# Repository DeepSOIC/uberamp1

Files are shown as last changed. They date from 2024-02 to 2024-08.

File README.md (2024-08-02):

# Feautures

* output channels: 8 independent(*) single-ended power outputs (TPA3255) + 2 headphone-amplified output channels + 2 non-amplified adau1701 dacs
    * independent 8 single-ended outputs can be arbitrarily combined into btl or even 3-phase-like arrangements.
    * BTL protections of the tpa chip can be enabled with solder bridges on the board
* two tpa3255 amps with full coverage of their supply range and peak output current(**)
* easy-to-program yet flexible adau1701 dsp chip, with self-boot memory on the board
* low-noise AK4454 dacs allow to use the full 113db(***) of dynamic range of the TPA3255
* 2 "feedbass" amplifiers on board, and places for resistors for custom analog mixing of feedbass into outputs.
* capacitor-free analog signal path (except analog inputs) allows to output dc, so uberamp1 can be used to drive motors
* 2 analog input channels
* bluetooth receiver with digital connection to the dsp (firmware = TODO)
* pads for summing inputs for each amp channel to allow adding custom analog feedbacks

(*) there is no place for decoupling capacitors on the board. So you might use one of the outputs as "ground", leaving you with 7 channels. In BTL, there are 4 output channels.

(**) at high supply voltage or high load currents, heatsinking becomes a challenge. It dissipates about 11W total in silence at 48 V.

(***) 113db is for BTL only. In SE mode, or across amps, the dynamic range of TPA3255 is much lower at 101 db.

# known problems (v1):

* power amps don't start exactly in sync, causing large excursion at powerup if a speaker is connected between amps. Seems unfixable.
* i don't have a good heat sink solution yet.
* dacs don't start up if the supply is raised slowly. Can be fixed with a bodge wire connecting "pg" net to "pd" pins of the dac chips
* it is very challenging to solder.

# soldering 

TLDR: manufacturability is screwed up on v1.

While the board was designed for hand-soldering, the footprints for 0603 passives turned out to not work well for hand-soldering.
It is further exacerbated by some bad placements - some pads are unreachable with a reasonable soldering iron. 
It seems that a lot of 0603 footprints can instead be populated with 0402 parts, that should make hand-soldering somewhat easier...

Reflow soldering for passives whould probably work well... but some other foorprints are completely unusable for reflow soldering.

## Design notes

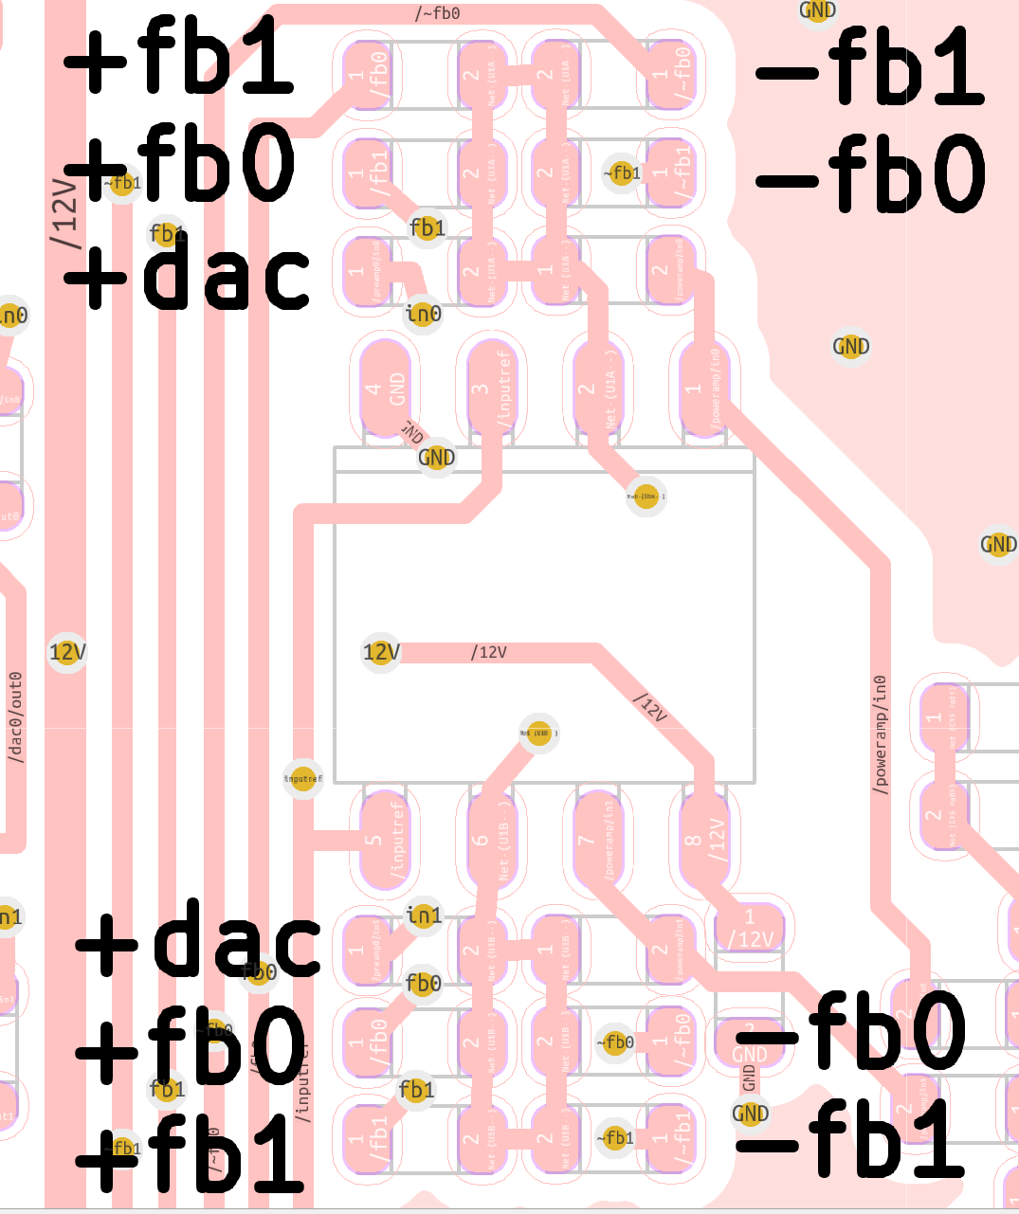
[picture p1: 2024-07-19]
summation resistor layout.png

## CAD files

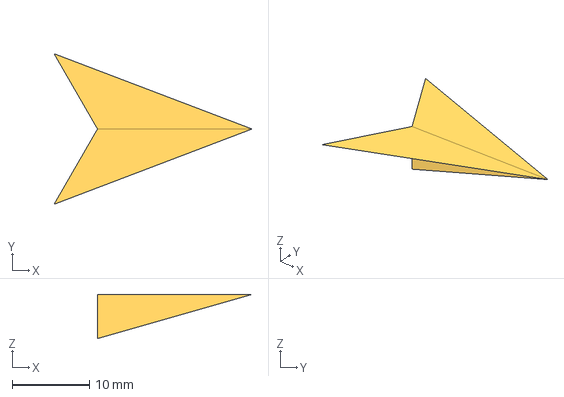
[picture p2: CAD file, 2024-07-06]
board outline.FCStd
25.6 x 19.5 x 5.71 mm

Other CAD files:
board outline.dxf

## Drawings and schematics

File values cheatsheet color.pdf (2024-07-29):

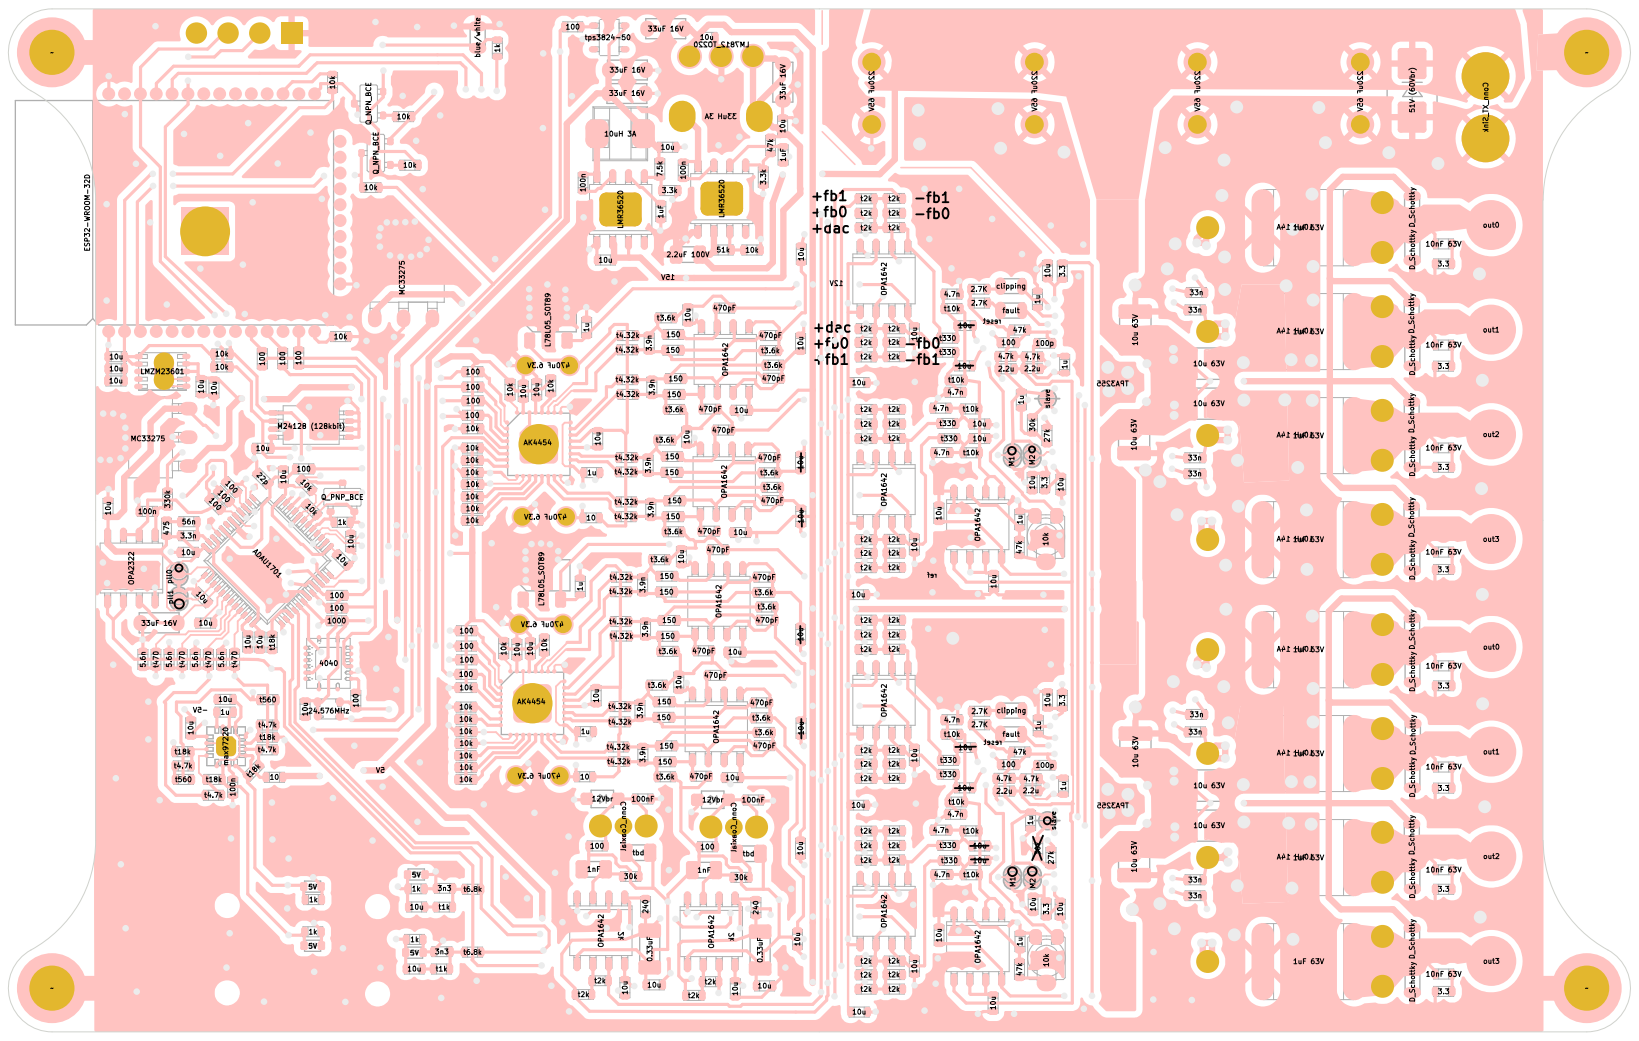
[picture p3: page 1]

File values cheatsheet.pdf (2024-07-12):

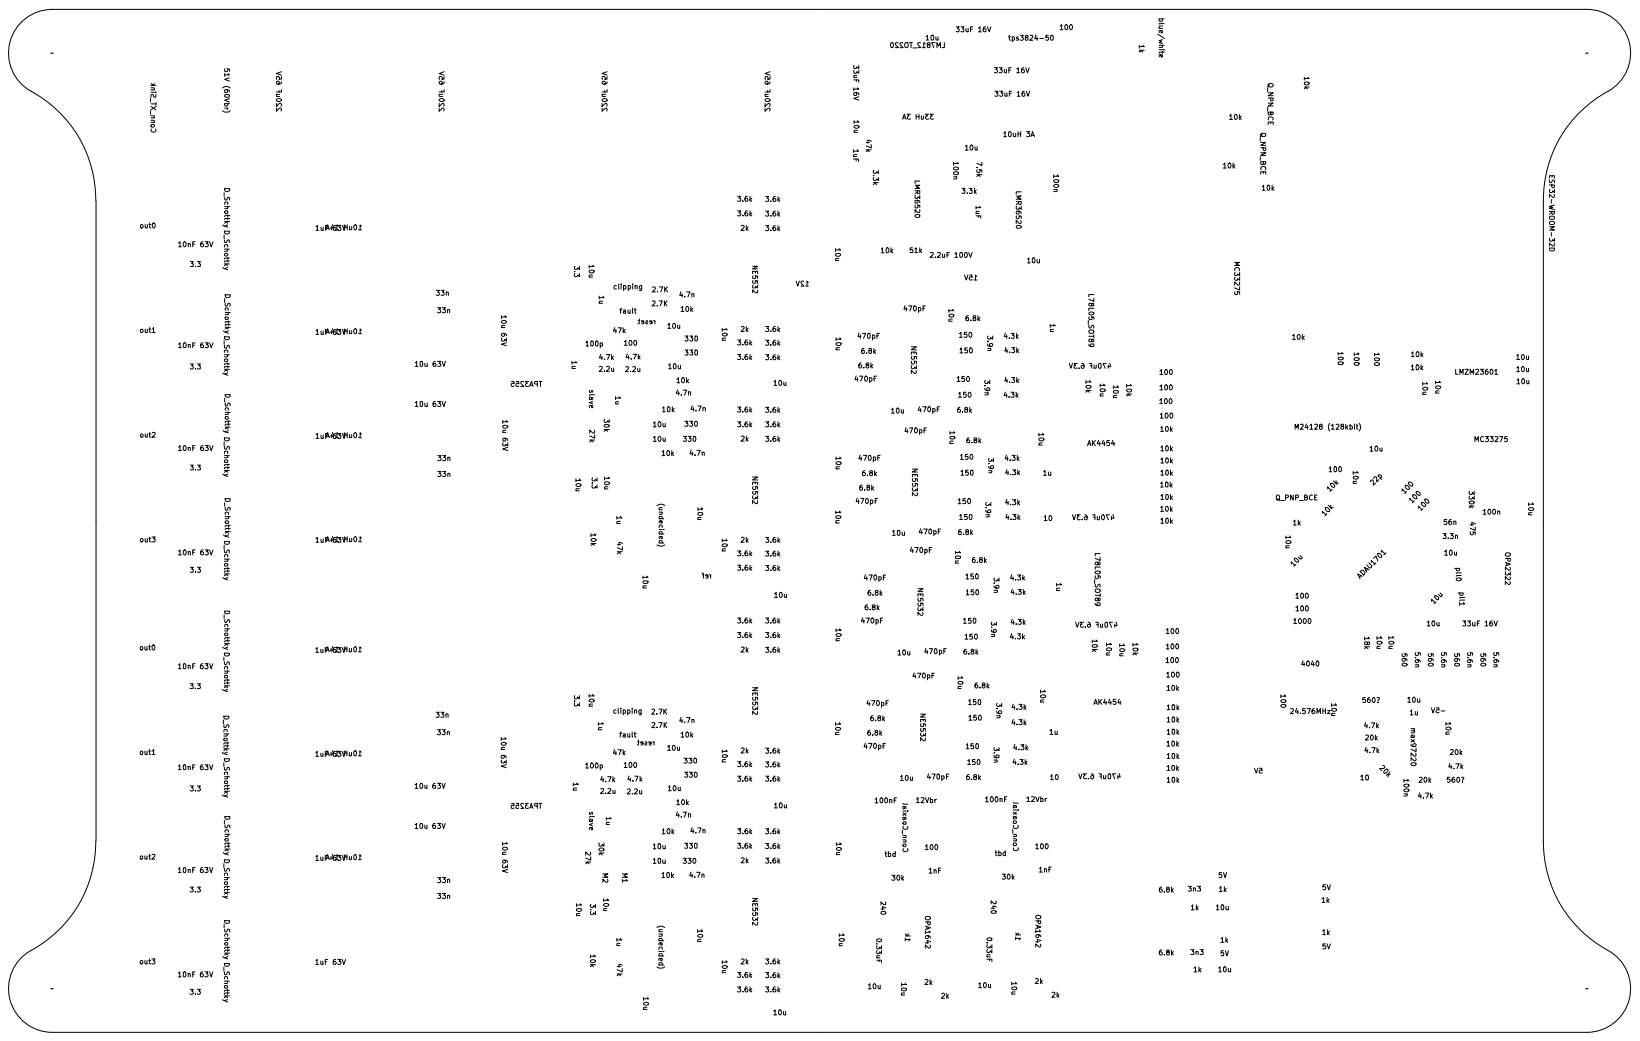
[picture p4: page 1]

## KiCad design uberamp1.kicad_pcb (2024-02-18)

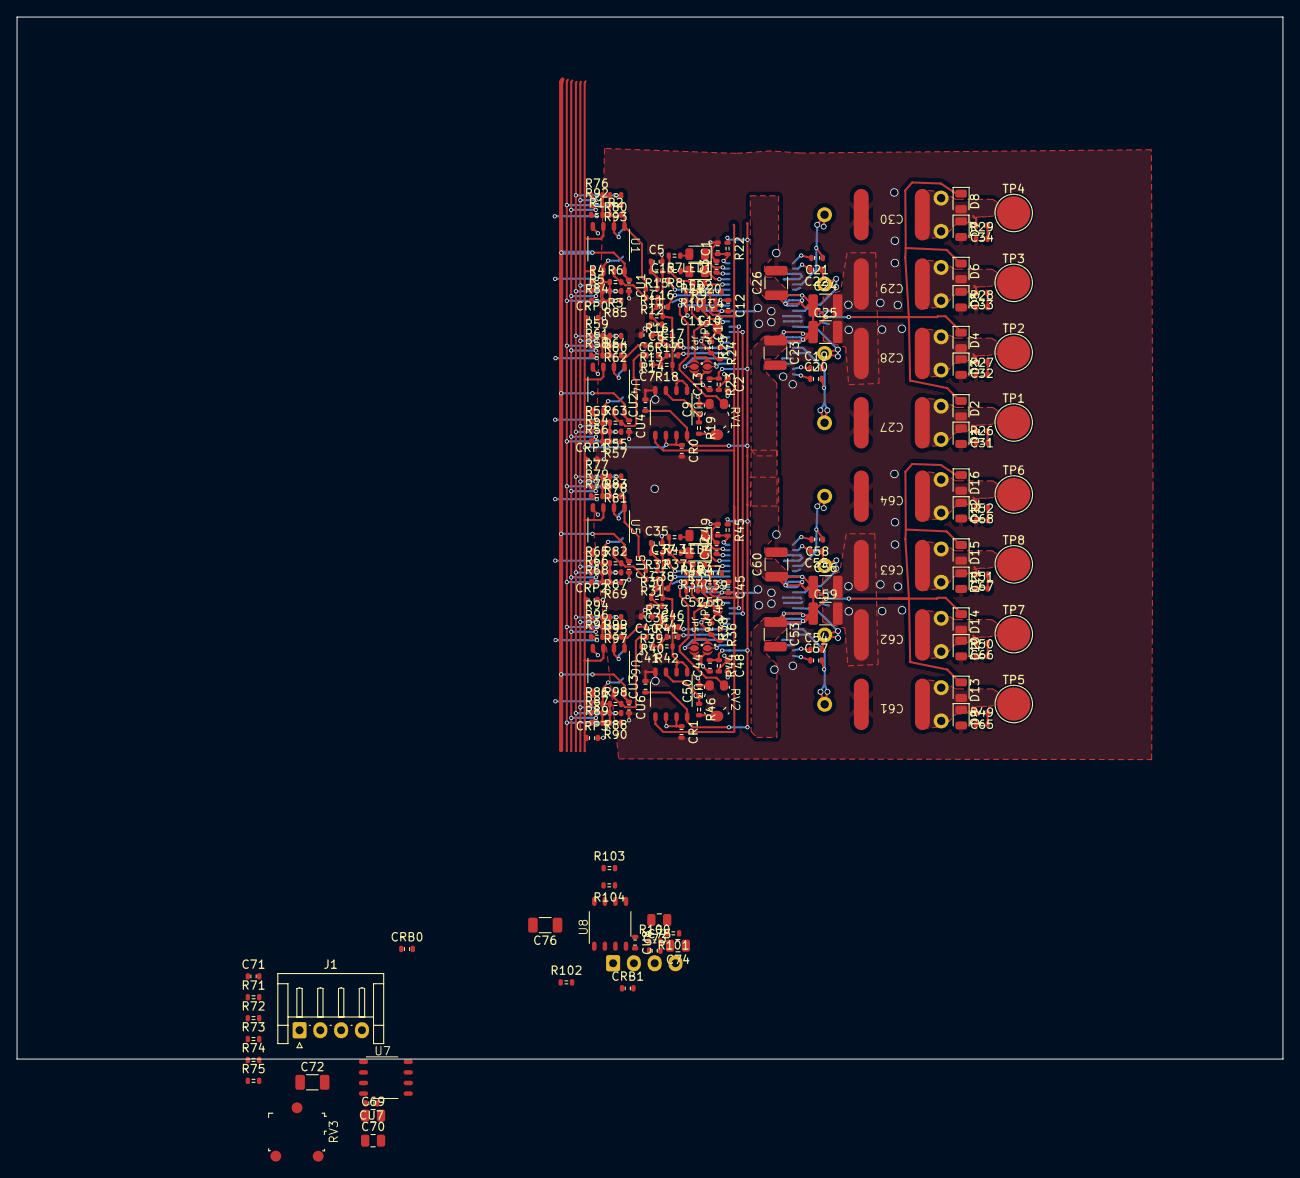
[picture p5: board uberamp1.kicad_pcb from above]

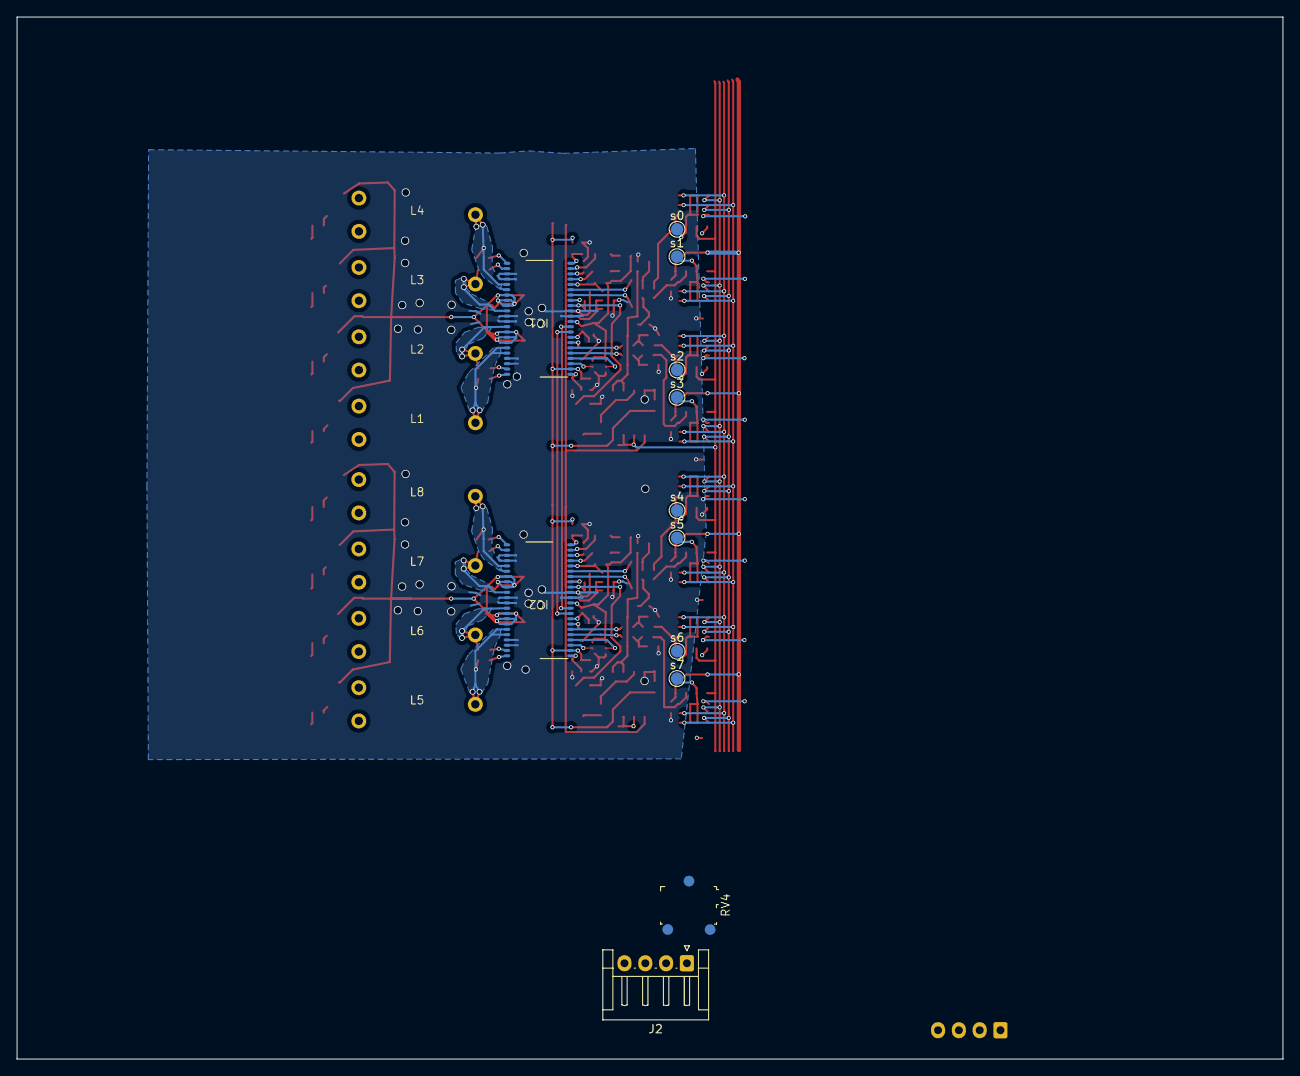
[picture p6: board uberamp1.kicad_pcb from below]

Board: 2 copper layers, 152.1 x 125.2 mm, 262 parts (20 on the bottom side), 124 nets.

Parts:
C1, C2, C13, C15, C16, C17, C18, C37, C38, C44, C46, C47, C48, C49: 10u; C_0603
C3, C9, C12, C42, C45, C50: 1u; C_0603
C4, C39: 100p; C_0603
C5, C6, C7, C8, C35, C36, C40, C41: 4.7n; C_0603
C10, C11, C51, C52: 2.2u; C_0603
C14, C43: 1uF; C_0603
C19, C20, C21, C22, C54, C55, C57, C58: 33n; C_0603
C23, C24, C25, C26, C53, C56, C59, C60: 10u 63V; C_1210_3225Metric
C27, C28, C29, C30, C61, C62, C63, C64: 1uF 63V; CB052D0105KBC film cap
C31, C32, C33, C34, C65, C66, C67, C68: 10nF; C_0603
C69, C74: tbd; C_0805_2012Metric
C70, C75: 1nF; C_0805_2012Metric
C71, C73: 100nF; C_0603
C72, C76: 0.33uF; C_1206_3216Metric
CR0, CR1: 10u; C_0603
CRB0, CRB1: 10u; C_0603
CRP0, CRP1, CRP2, CRP3: 10u; C_0603
CU1, CU2, CU3, CU4, CU5, CU6, CU7, CU8: 10u; C_0603
D1, D2, D3, D4, D5, D6, D7, D8, D9, D10, D11, D12, D13, D14, D15, D16: D_Schottky; D_0805_2012Metric
IC1, IC2: TPA3255; tssop44-powerpad
J1, J2: Conn_01x04; JST_EH_S4B-EH_1x04_P2.50mm_Horizontal
JP1, JP2, JP5, JP6: SolderJumper_3_Bridged12; solder-switch
JP3, JP4: slave; solder-jumper
L1, L2, L3, L4, L5, L6, L7, L8: 10uH 14A; SPM12565VT-D-vertical
LED1, LED4: clipping; LED_0805_2012Metric
LED2, LED3: fault; LED_0805_2012Metric
R1, R4, R53, R58, R65, R70, R86, R91: R_Small; R_0603
R2, R6, R63, R64, R71, R72, R82, R83, R98, R99, R103, R104: 2k; R_0603
R3, R5, R54, R55, R56, R57, R59, R60, R61, R62, R66, R67, R68, R69, R76, R77, R78, R79, R80, R81, R84, R85, R87, R88, R89, R90, R92, R93, R94, R95, R96, R97: 3.6k; R_0603
R7, R8, R37, R43: 2.7K; R_0603
R9, R19, R35, R46: 47k; R_0603
R10, R34, R75, R100: 100; R_0603
R11, R12, R13, R14, R30, R31, R39, R40: 330; R_0603
R15, R16, R17, R18, R32, R33, R41, R42: 10k; R_0603
R20, R21, R47, R48: 4.7k; R_0603
R22, R23, R26, R27, R28, R29, R44, R45, R49, R50, R51, R52: 3.3; R_0603
R24, R36: 27k; R_0603
R25, R38, R73, R101: 30k; R_0603
R74, R102: 240; R_0603
RV1, RV2: 10k; TC33X-2 trimpot
RV3, RV4: 1k; PV37X
TP1, TP5: out3; TestPoint_Pad_D4.0mm
TP2, TP7: out2; TestPoint_Pad_D4.0mm
TP3, TP8: out1; TestPoint_Pad_D4.0mm
TP4, TP6: out0; TestPoint_Pad_D4.0mm
U1, U2, U3, U4, U5, U6, U7, U8: Opamp_Dual; SOIC-8
s0, s1, s2, s3, s4, s5, s6, s7: sum0; TestPoint_Pad_D1.5mm

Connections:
/12V: C13.2, C44.2, CU1.1, CU2.1, CU3.1, CU4.1, CU5.1, CU6.1, CU7.1, CU8.1, IC1.2 (2_VDD), IC2.2 (2_VDD), R22.1, R23.1, R44.1, R45.1, U1.8 (V+), U2.8 (V+), U3.8 (V+), U4.8 (V+), U5.8 (V+), U6.8 (V+), U7.8 (V+), U8.8 (V+)
/fb0: C72.1, R5.1, R54.1, R59.1, R66.1, R71.1, R74.2, R76.1, R77.1, R87.1, R94.1
/fb1: C76.1, R56.1, R61.1, R68.1, R79.1, R84.1, R89.1, R92.1, R96.1, R102.2, R103.1
/inputref: C69.2, C70.2, C72.2, C74.2, C75.2, C76.2, CR0.1, CRB0.1, CRB1.1, CRP0.1, CRP1.1, CRP2.1, CRP3.1, R75.2, R100.2, RV3.3, RV4.3, U1.3 (+), U1.5 (+), U2.6 (-), U2.7, U4.3 (+), U4.5 (+), U5.3 (+), U5.5 (+), U6.3 (+), U6.5 (+), U7.5 (+), U8.5 (+)
/poweramp1/AVDD: C51.1, IC2.14 (14_AVDD), R47.2, RV2.3
/poweramp1/DVDD: C43.1, IC2.11 (11_DVDD), JP4.2 (B), JP5.1 (A), JP6.1 (A), R35.2, R37.2, R43.2
/poweramp1/in0: R30.2, R83.2, U5.1
/poweramp1/in1: R31.2, R82.2, U5.7
/poweramp1/in2: R39.2, R99.2, U6.1
/poweramp1/in3: R40.2, R98.2, U6.7
/poweramp1/in_a: C47.2, IC2.5 (5_INPUT_A)
/poweramp1/in_b: C46.2, IC2.6 (6_INPUT_B)
/poweramp1/in_c: C38.2, IC2.16 (16_INPUT_C)
/poweramp1/in_d: C37.2, IC2.17 (17_INPUT_D)
/poweramp1/input_ref: CR1.1, U3.6 (-), U3.7
/poweramp1/out0: C64.1, C68.2, D12.1 (K), D16.2 (A), L8.1, TP6.1
/poweramp1/out1: C63.1, C67.2, D11.1 (K), D15.2 (A), L7.1, TP8.1
/poweramp1/out2: C62.1, C66.2, D10.1 (K), D14.2 (A), L6.1, TP7.1
/poweramp1/out3: C61.1, C65.2, D9.1 (K), D13.2 (A), L5.1, TP5.1
/poweramp1/sw0: C58.1, IC2.27 (27_OUT_D), IC2.28 (28_OUT_D____________), L8.2
/poweramp1/sw1: C55.1, IC2.32 (32_OUT_C), L7.2
/poweramp1/sw2: C54.2, IC2.35 (35_OUT_B), L6.2
/poweramp1/sw3: C57.2, IC2.39 (39_OUT_A), IC2.40 (40_OUT_A____________), L5.2
/poweramp1/trim: R32.1, R33.1, R41.1, R42.1, U3.1, U3.2 (-)
/poweramp/AVDD: C10.1, IC1.14 (14_AVDD), R20.2, RV1.3
/poweramp/DVDD: C14.1, IC1.11 (11_DVDD), JP1.1 (A), JP2.1 (A), JP3.2 (B), R7.2, R8.2, R9.2
/poweramp/in0: R2.2, R11.2, U1.1
/poweramp/in1: R6.2, R12.2, U1.7
/poweramp/in2: R13.2, R64.2, U4.1
/poweramp/in3: R14.2, R63.2, U4.7
/poweramp/in_a: C18.2, IC1.5 (5_INPUT_A)
/poweramp/in_b: C17.2, IC1.6 (6_INPUT_B)
/poweramp/in_c: C16.2, IC1.16 (16_INPUT_C)
/poweramp/in_d: C15.2, IC1.17 (17_INPUT_D)
/poweramp/input_ref_z: C10.2, C11.1, C51.2, C52.1, R20.1, R21.2, R47.1, R48.2, U2.5 (+), U3.5 (+)
/poweramp/osc+: IC1.10 (10_OSC_IOP), IC2.10 (10_OSC_IOP)
/poweramp/osc-: IC1.9 (9_OSC_IOM), IC2.9 (9_OSC_IOM)
/poweramp/out0: C30.1, C34.2, D7.1 (K), D8.2 (A), L4.1, TP4.1
/poweramp/out1: C29.1, C33.2, D5.1 (K), D6.2 (A), L3.1, TP3.1
/poweramp/out2: C28.1, C32.2, D3.1 (K), D4.2 (A), L2.1, TP2.1
/poweramp/out3: C27.1, C31.2, D1.1 (K), D2.2 (A), L1.1, TP1.1
/poweramp/sw0: C21.1, IC1.27 (27_OUT_D), IC1.28 (28_OUT_D____________), L4.2
/poweramp/sw1: C22.1, IC1.32 (32_OUT_C), L3.2
/poweramp/sw2: C19.2, IC1.35 (35_OUT_B), L2.2
/poweramp/sw3: C20.2, IC1.39 (39_OUT_A), IC1.40 (40_OUT_A____________), L1.2
/poweramp/trim: R15.1, R16.1, R17.1, R18.1, U2.1, U2.2 (-)
/~fb0: R3.1, R55.1, R60.1, R67.1, R72.2, R78.1, R80.1, R88.1, R95.1, U7.7
/~fb1: R57.1, R62.1, R69.1, R81.1, R85.1, R90.1, R93.1, R97.1, R104.2, U8.7
GND: C1.2, C2.2, C3.2, C4.2, C5.2, C6.2, C7.2, C8.2, C9.2, C11.2, C12.2, C13.1, C14.2, C23.2, C24.2, C25.2, C26.2, C27.2, C28.2, C29.2, C30.2, C35.2, C36.2, C39.2, C40.2, C41.2, C42.2, C43.2, C44.1, C45.2, C48.2, C49.2, C50.2, C52.2, C53.2, C56.2, C59.2, C60.2, C61.2, C62.2, C63.2, C64.2, C71.2, C73.2, CR0.2, CR1.2, CRB0.2, CRB1.2, CRP0.2, CRP1.2, CRP2.2, CRP3.2, CU1.2, CU2.2, CU3.2, CU4.2, CU5.2, CU6.2, CU7.2, CU8.2, D1.2 (A), D3.2 (A), D5.2 (A), D7.2 (A), D9.2 (A), D10.2 (A), D11.2 (A), D12.2 (A), IC1.12 (12_GND), IC1.13 (13_GND), IC1.25 (25_GND), IC1.26 (26_GND), IC1.33 (33_GND), IC1.34 (34_GND), IC1.41 (41_GND), IC1.42 (42_GND), IC2.12 (12_GND), IC2.13 (13_GND), IC2.25 (25_GND), IC2.26 (26_GND), IC2.33 (33_GND), IC2.34 (34_GND), IC2.41 (41_GND), IC2.42 (42_GND), JP1.3 (B), JP2.3 (B), JP5.3 (B), JP6.3 (B), R21.1, R24.2, R25.2, R26.1, R27.1, R28.1, R29.1, R36.2, R38.2, R48.1, R49.1, R50.1, R51.1, R52.1, RV1.1, RV2.1, U1.4 (V-), U2.4 (V-), U3.4 (V-), U4.4 (V-), U5.4 (V-), U6.4 (V-), U7.4 (V-), U8.4 (V-)
unnamed: C5.1, C15.1, R11.1, R15.2
unnamed: C8.1, C16.1, R12.1, R16.2
unnamed: C6.1, C17.1, R13.1, R17.2
unnamed: C7.1, C18.1, R14.1, R18.2
unnamed: C31.1, R26.2
unnamed: C32.1, R27.2
unnamed: C33.1, R28.2
unnamed: C34.1, R29.2
unnamed: C35.1, C37.1, R30.1, R32.2
unnamed: C36.1, C38.1, R31.1, R33.2
unnamed: C40.1, C46.1, R39.1, R41.2
unnamed: C41.1, C47.1, R40.1, R42.2
unnamed: C65.1, R49.2
unnamed: C66.1, R50.2
unnamed: C67.1, R51.2
unnamed: C68.1, R52.2
unnamed: C2.1, IC1.1 (1_GVDD_AB), R23.2
unnamed: IC1.3 (3_M1), JP1.2 (C)
unnamed: IC1.4 (4_M2), JP2.2 (C)
unnamed: IC1.7 (7_OC_ADJ), R24.1
unnamed: IC1.8 (8_FREQ_ADG), JP3.1 (A), R25.1
unnamed: C12.1, IC1.15 (15_C_START)
unnamed: C4.1, IC1.18 (18_RESET), R9.1, R10.1
unnamed: IC1.19 (19_FAULT), LED2.1 (K)
unnamed: C3.1, IC1.20 (20_VBG)
unnamed: IC1.21 (21_CLIP_OTW), LED1.1 (K)
unnamed: C1.1, IC1.22 (22GVDD_CD), R22.2
unnamed: C21.2, IC1.23 (23_BST_D)
unnamed: C22.2, IC1.24 (24_BST_C)
unnamed: C19.1, IC1.43 (43_BST_B)
unnamed: C20.1, IC1.44 (44_BST_A)
unnamed: C48.1, IC2.1 (1_GVDD_AB), R44.2
unnamed: IC2.3 (3_M1), JP6.2 (C)
unnamed: IC2.4 (4_M2), JP5.2 (C)
unnamed: IC2.7 (7_OC_ADJ), R36.1
unnamed: IC2.8 (8_FREQ_ADG), JP4.1 (A), R38.1
unnamed: C45.1, IC2.15 (15_C_START)
unnamed: C39.1, IC2.18 (18_RESET), R34.1, R35.1
unnamed: IC2.19 (19_FAULT), LED3.1 (K)
unnamed: C42.1, IC2.20 (20_VBG)
unnamed: IC2.21 (21_CLIP_OTW), LED4.1 (K)
unnamed: C49.1, IC2.22 (22GVDD_CD), R45.2
unnamed: C58.2, IC2.23 (23_BST_D)
unnamed: C55.2, IC2.24 (24_BST_C)
unnamed: C54.1, IC2.43 (43_BST_B)
unnamed: C57.1, IC2.44 (44_BST_A)
unnamed: C71.1, J1.3, R75.1
unnamed: C69.1, J1.4, R73.1
unnamed: C73.1, J2.3, R100.1
unnamed: C74.1, J2.4, R101.1
unnamed: LED1.2 (A), R7.1
unnamed: LED2.2 (A), R8.1
unnamed: LED3.2 (A), R37.1
unnamed: LED4.2 (A), R43.1
unnamed: R19.2, RV1.2
unnamed: R46.2, RV2.2
unnamed: R74.1, RV3.1, U7.1
unnamed: R102.1, RV4.1, U8.1
unnamed: R1.2, R2.1, R76.2, R80.2, R92.2, R93.2, U1.2 (-), s0.1
unnamed: R3.2, R4.2, R5.2, R6.1, R84.2, R85.2, U1.6 (-), s1.1
unnamed: C9.1, R19.1, U2.3 (+)
unnamed: C50.1, R46.1, U3.3 (+)
unnamed: R58.2, R59.2, R60.2, R61.2, R62.2, R64.1, U4.2 (-), s2.1
unnamed: R53.2, R54.2, R55.2, R56.2, R57.2, R63.1, U4.6 (-), s3.1
unnamed: R70.2, R77.2, R78.2, R79.2, R81.2, R83.1, U5.2 (-), s4.1
unnamed: R65.2, R66.2, R67.2, R68.2, R69.2, R82.1, U5.6 (-), s5.1
unnamed: R91.2, R94.2, R95.2, R96.2, R97.2, R99.1, U6.2 (-), s6.1
unnamed: R86.2, R87.2, R88.2, R89.2, R90.2, R98.1, U6.6 (-), s7.1
unnamed: C70.1, R73.2, U7.3 (+)
unnamed: RV3.2, U7.2 (-)
unnamed: R71.2, R72.1, U7.6 (-)
unnamed: C75.1, R101.2, U8.3 (+)
unnamed: RV4.2, U8.2 (-)
unnamed: R103.2, R104.1, U8.6 (-)
PVDD: C23.1, C24.1, C25.1, C26.1, C53.1, C56.1, C59.1, C60.1, D2.1 (K), D4.1 (K), D6.1 (K), D8.1 (K), D13.1 (K), D14.1 (K), D15.1 (K), D16.1 (K), IC1.29 (29_PVDD_CD), IC1.30 (30_PVDD_CD), IC1.31 (31_PVDD_CD), IC1.36 (36_PVDD_AB), IC1.37 (37_PVDD_AB), IC1.38 (38_PVDD_AB), IC2.29 (29_PVDD_CD), IC2.30 (30_PVDD_CD), IC2.31 (31_PVDD_CD), IC2.36 (36_PVDD_AB), IC2.37 (37_PVDD_AB), IC2.38 (38_PVDD_AB)

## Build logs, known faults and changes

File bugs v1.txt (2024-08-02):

bugs:
* all gains wrong because 8.8vpp is unachievable because fakegnd is only 3.82V
* NE5532 unusable (can't quite swing close enough to ground - need to reach 1.44 V, promised only 2 V). Using OPA1642 for now.
* with modified gains, the overall gain seems to be excessive. (check again!)
* r187 wrong value, should be 13k
* ak4454 NEEDS pg signal, otherwise it fails to start when supply raises slowly
* middle cap next to adau is very hard to solder
* caps to the left of dac amp are difficult to solder
* 10u caps are a bit larger than the footprint
* wrong footprint ak caps
* consider using 0402 on my 0603 footprints
* revise jack footprint:
  * make pads larger for more robustness
  * alignment holes are too large
* feedbass is missing the discharge resistor (but can be soldered instead of the shunt cap)
* feedbass trimpot turn direction is backwards
* wrong stencil opening under lmr chips
* 3.3v ldo for digital side is not needed because we have an LMZM for esp32 already
* 7812 gets quite hot. Replace with a capacitor amplifier?
* startup of two amps is not synchronized, causing massive excursion if a speaker is connected across the amps
* need protection on i2c and low voltage supplies OR use pixhawk connector

cosmetic bugs:
* wrong silkscreen on 0805 caps
* lmzm pin1 not marked
* 5v pad label placement
* indicate thin-film resistors on the schematic 
* add silkscreen for summation resistors (there is space)
* add ouput channel numbers silkscreen
* fix fb0 fb1 confusion (HOW CAN IT BE SOOO TOTALLY BROKEN ???)

other todos
* add holes under tpa chips for checking their temperature with a thermal cam
* design a heatsink mount
* add another i2c connector footprint for standalone adau

potential replacement el-cheapo opamp: MC33078DR2G

need more parts:
OPA1642
MC33078DR2G
3.9nF NP0
3.3nF NP0
ESD5B5V0WT
jst gh connectors of right orientation BM06B-GHS-TBT

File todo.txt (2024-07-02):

* add fakegnd pads
* add some test pads

last steps:
* check there are no through-hole connections to ground plane
* some pads need solid connections
* check pvdd vias
* remove all silkscreen text
* .. but make sure pads have labels

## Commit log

2024-02-18 about to breaking change
    state of things prior to switching poweramp instances in schematic
    [feedbass_preamp.kicad_sch, poweramp.kicad_sch, preamp.kicad_sch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]
2024-02-18 add bypass caps to opamps + swap poweramps + layout progress
    [feedbass_preamp.kicad_sch, poweramp.kicad_sch, preamp.kicad_sch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]
2024-02-18 route 1 preamp
    [preamp.kicad_sch, uberamp1.kicad_pcb, uberamp1.kicad_sch]
2024-02-18 route all preamps
    [uberamp1.kicad_pcb]
2024-02-18 add bypass caps to fakegnd
    [feedbass_preamp.kicad_sch, poweramp.kicad_sch, preamp.kicad_sch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]
2024-02-18 update feedbass components
    [feedbass_preamp.kicad_sch, uberamp1.kicad_pcb]
2024-02-18 fix feedbass filter
    [feedbass_preamp.kicad_sch, uberamp1.kicad_pcb]
2024-02-29 add dacs to schematic
    [dac.kicad_sch, dac_amp.kicad_sch, uberamp1.kicad_sch]
2024-03-03 minor schematic updates
    [poweramp.kicad_sch, preamp.kicad_sch]
2024-03-03 add step-down regulators to schematic
    [supplies.kicad_sch, uberamp1.kicad_sch]
2024-03-04 tweak supplies schematic
    [supplies.kicad_sch]
2024-03-04 add clock source to schematic
    [uberamp1.kicad_sch]
2024-06-20 add dsp and esp32... schematic mostly done
    [audio_input.kicad_sch, dac.kicad_sch, dsp.kicad_sch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]
2024-06-21 update to kicad 8
    [audio_input.kicad_sch, dac.kicad_sch, dac_amp.kicad_sch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]
2024-06-23 schematic: some fixes
    [dac.kicad_sch, dac_amp.kicad_sch, dsp.kicad_sch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]
2024-06-23 updates
    * add line out
    * fix almost all erc
    * some more random edits
    [audio_input.kicad_sch, dsp.kicad_sch, esp32.kicad_sch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]
2024-06-30 add power input +...
    + tons of fixes, footprint assignments, etc
    [audio_input.kicad_sch, dac.kicad_sch, dac_amp.kicad_sch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]
2024-07-02 some routing till got stuck
    got stuck on U16's power part somehow being on a different sheet
    [dac.kicad_sch, feedbass_preamp.kicad_sch]
2024-07-02 fix gate association U15 U16
    [dac_amp.kicad_sch, dsp.kicad_sch]
2024-07-02 routing...
    + swap around dac channels, otherwise routing was crazy
    [dac.kicad_sch, esp32.kicad_sch, supplies.kicad_sch]
2024-07-04 routing routing...
    [dsp.kicad_sch, line_out.kicad_sch]
2024-07-06 lots of drc-related work
    [dsp.kicad_sch, esp32.kicad_sch, supplies.kicad_sch]
2024-07-06 update some footprints
    [esp32.kicad_sch, feedbass_preamp.kicad_sch, poweramp.kicad_sch]
2024-07-06 silkscreen works + fixes
2024-07-06 more silkscreen
2024-07-06 tweaks
    round size
    add some new pads
    [supplies.kicad_sch]
2024-07-06 board outline
    + fix voltage range label
    [board outline.FCStd, board outline.dxf, uberamp1.kicad_sch]
2024-07-07 final touches. Sent for production.
    [uberamp1.kicad_sch]
2024-07-08 fix board edge clearance
2024-07-08 fill in some part numbers
    [audio_input.kicad_sch, dac.kicad_sch, dac_amp.kicad_sch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]
2024-07-12 bom config
2024-07-12 update partnumbers to what was bought
    [dac_amp.kicad_sch, dsp.kicad_sch, esp32.kicad_sch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]
2024-07-12 print cheatsheets
    [poweramp.kicad_sch]
2024-07-19 add summation resistor layout cheatsheet
2024-07-19 workaround major gain/signal margin error
    using the components i have at hand. There probably are better options. Next revision should make use of the -5v rail.
    [dac_amp.kicad_sch, feedbass_preamp.kicad_sch, poweramp.kicad_sch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]
2024-07-29 update values to what's being used + mark thin film resistors
    [audio_input.kicad_sch, dsp.kicad_sch, line_out.kicad_sch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]
